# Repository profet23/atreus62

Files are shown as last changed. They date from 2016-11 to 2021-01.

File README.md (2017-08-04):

# atreus62
Design files for the atreus62 keyboard

[Atreus62 components can be purchased from the online store.](http://shop.profetkeyboards.com/category/atreus62)

This keyboad is inspired by the original [atreus keyboard](https://atreus.technomancy.us/).

This version utilizes a Pro Micro for its controller and has a 62 key layout.

## [Build Guide](build-guide/)

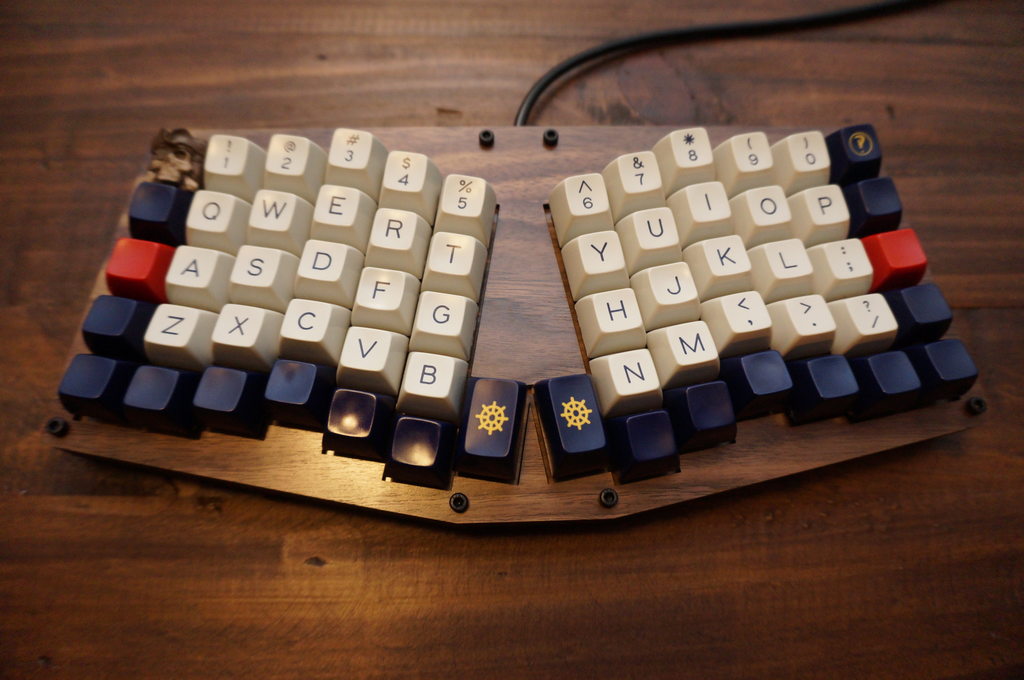
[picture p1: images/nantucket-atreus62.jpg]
Nantucket atreus62


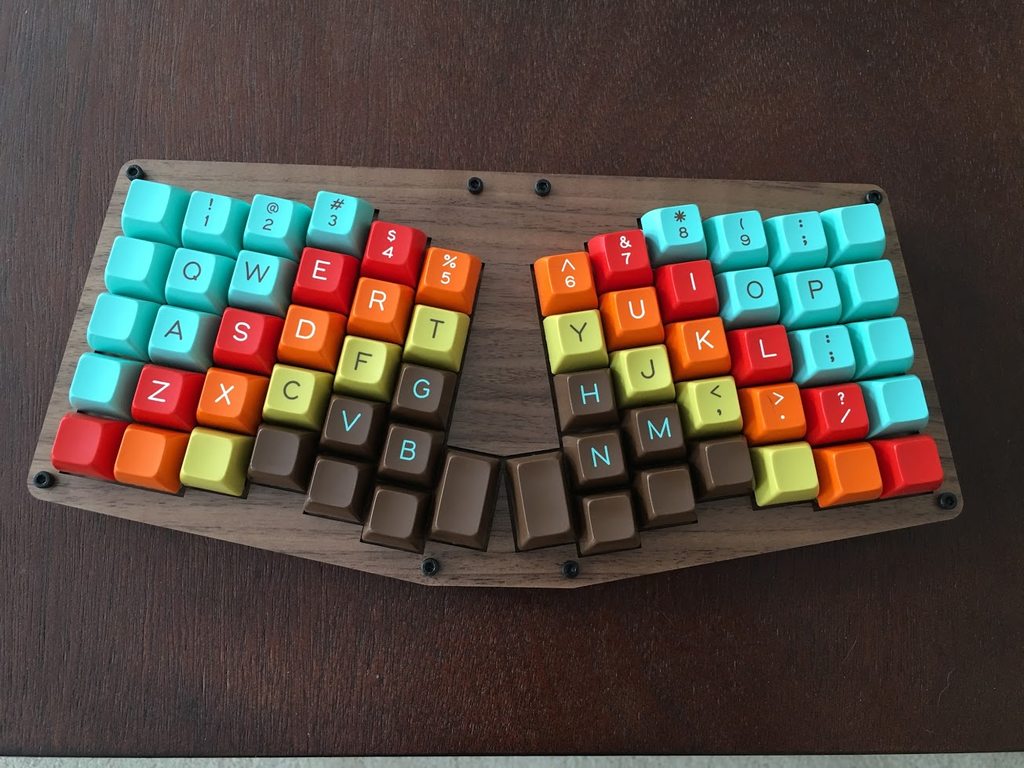
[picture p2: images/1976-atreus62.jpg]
1976 atreus62


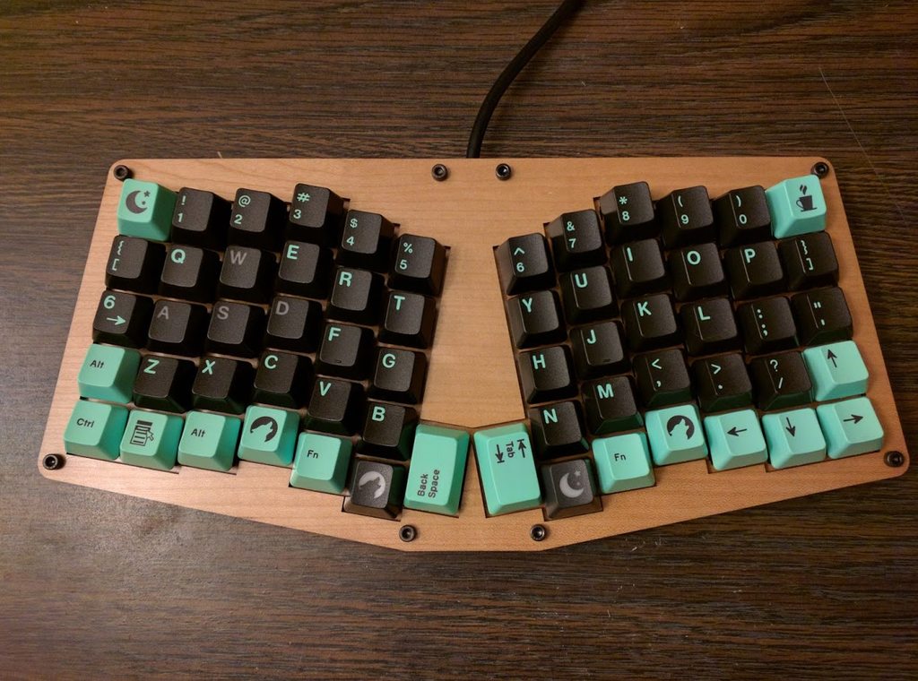
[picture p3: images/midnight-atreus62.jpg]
Midnight atreus62


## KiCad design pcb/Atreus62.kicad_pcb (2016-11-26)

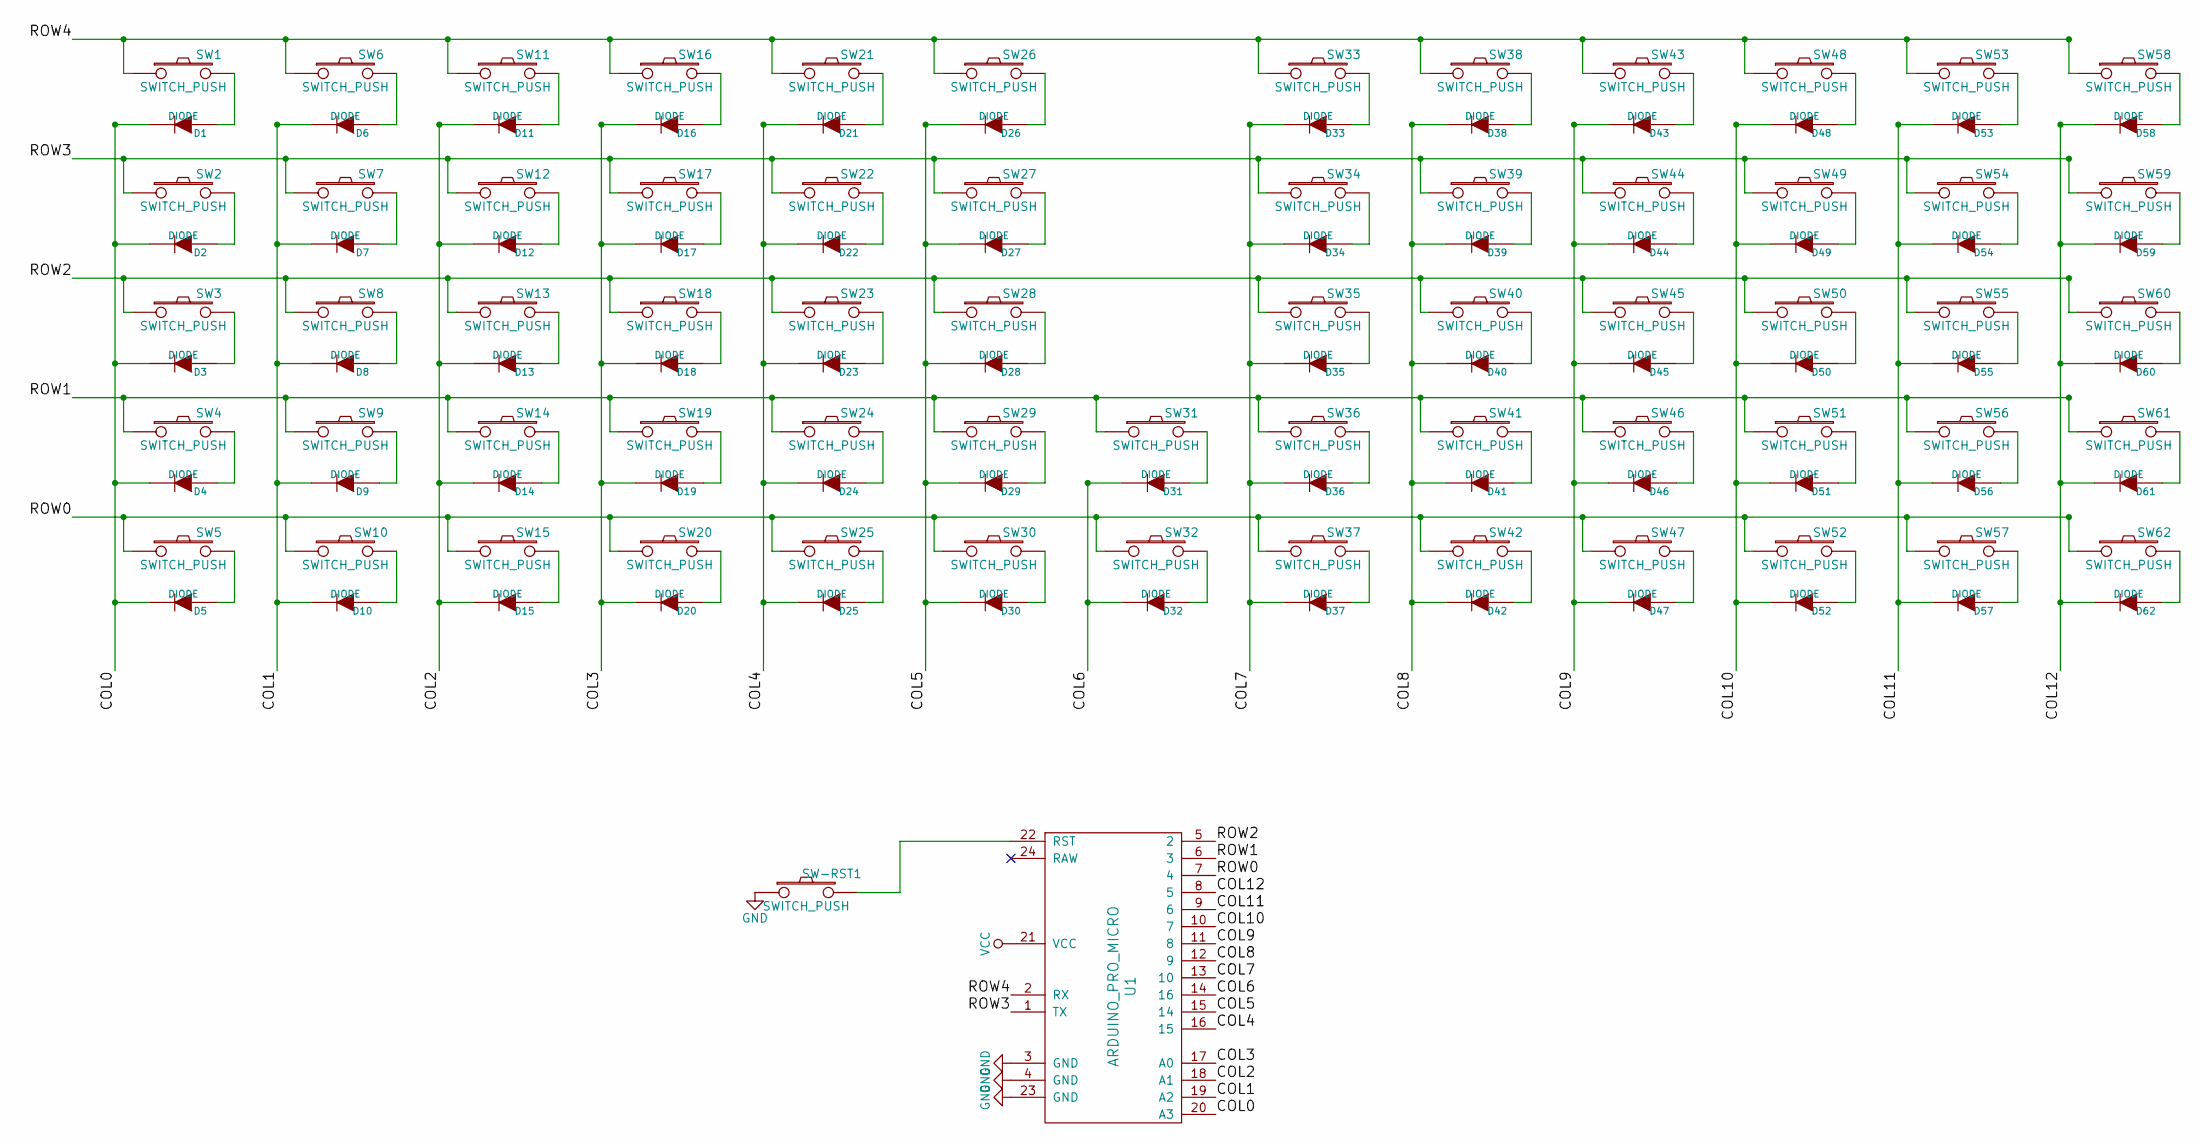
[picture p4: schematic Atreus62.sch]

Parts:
D1, D2, D3, D4, D5, D6, D7, D8, D9, D10, D11, D12, D13, D14, D15, D16, D17, D18, D19, D20, D21, D22, D23, D24, D25, D26, D27, D28, D29, D30, D31, D32, D33, D34, D35, D36, D37, D38, D39, D40, D41, D42, D43, D44, D45, D46, D47, D48, D49, D50, D51, D52, D53, D54, D55, D56, D57, D58, D59, D60, D61, D62: DIODE; SOD-123
SW1, SW2, SW3, SW4, SW5, SW6, SW7, SW8, SW9, SW10, SW11, SW12, SW13, SW14, SW15, SW16, SW17, SW18, SW19, SW20, SW21, SW22, SW23, SW24, SW25, SW26, SW27, SW28, SW29, SW30, SW31, SW32, SW33, SW34, SW35, SW36, SW37, SW38, SW39, SW40, SW41, SW42, SW43, SW44, SW45, SW46, SW47, SW48, SW49, SW50, SW51, SW52, SW53, SW54, SW55, SW56, SW57, SW58, SW59, SW60, SW61, SW62: SWITCH_PUSH; CHERRY_PCB_100H
SW-RST1: SWITCH_PUSH; SW_SPST_B3U-1000P
U1: ARDUINO_PRO_MICRO

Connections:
/COL0: D1.2 (K), D2.2 (K), D3.2 (K), D4.2 (K), D5.2 (K), U1.20 (A3)
/COL1: D6.2 (K), D7.2 (K), D8.2 (K), D9.2 (K), D10.2 (K), U1.19 (A2)
/COL2: D11.2 (K), D12.2 (K), D13.2 (K), D14.2 (K), D15.2 (K), U1.18 (A1)
/COL3: D16.2 (K), D17.2 (K), D18.2 (K), D19.2 (K), D20.2 (K), U1.17 (A0)
/COL4: D21.2 (K), D22.2 (K), D23.2 (K), D24.2 (K), D25.2 (K), U1.16 (15)
/COL5: D26.2 (K), D27.2 (K), D28.2 (K), D29.2 (K), D30.2 (K), U1.15 (14)
/COL6: D31.2 (K), D32.2 (K), U1.14 (16)
/COL7: D33.2 (K), D34.2 (K), D35.2 (K), D36.2 (K), D37.2 (K), U1.13 (10)
/COL8: D38.2 (K), D39.2 (K), D40.2 (K), D41.2 (K), D42.2 (K), U1.12 (9)
/COL9: D43.2 (K), D44.2 (K), D45.2 (K), D46.2 (K), D47.2 (K), U1.11 (8)
/COL10: D48.2 (K), D49.2 (K), D50.2 (K), D51.2 (K), D52.2 (K), U1.10 (7)
/COL11: D53.2 (K), D54.2 (K), D55.2 (K), D56.2 (K), D57.2 (K), U1.9 (6)
/COL12: D58.2 (K), D59.2 (K), D60.2 (K), D61.2 (K), D62.2 (K), U1.8 (5)
/ROW0: SW5.1, SW10.1, SW15.1, SW20.1, SW25.1, SW30.1, SW32.1, SW37.1, SW42.1, SW47.1, SW52.1, SW57.1, SW62.1, U1.7 (4)
/ROW1: SW4.1, SW9.1, SW14.1, SW19.1, SW24.1, SW29.1, SW31.1, SW36.1, SW41.1, SW46.1, SW51.1, SW56.1, SW61.1, U1.6 (3)
/ROW2: SW3.1, SW8.1, SW13.1, SW18.1, SW23.1, SW28.1, SW35.1, SW40.1, SW45.1, SW50.1, SW55.1, SW60.1, U1.5 (2)
/ROW3: SW2.1, SW7.1, SW12.1, SW17.1, SW22.1, SW27.1, SW34.1, SW39.1, SW44.1, SW49.1, SW54.1, SW59.1, U1.1 (TX)
/ROW4: SW1.1, SW6.1, SW11.1, SW16.1, SW21.1, SW26.1, SW33.1, SW38.1, SW43.1, SW48.1, SW53.1, SW58.1, U1.2 (RX)
GND: SW-RST1.1, U1.3 (GND), U1.4 (GND), U1.23 (GND)
unnamed: D1.1 (A), SW1.2
unnamed: D2.1 (A), SW2.2
unnamed: D3.1 (A), SW3.2
unnamed: D4.1 (A), SW4.2
unnamed: D5.1 (A), SW5.2
unnamed: D6.1 (A), SW6.2
unnamed: D7.1 (A), SW7.2
unnamed: D8.1 (A), SW8.2
unnamed: D9.1 (A), SW9.2
unnamed: D10.1 (A), SW10.2
unnamed: D11.1 (A), SW11.2
unnamed: D12.1 (A), SW12.2
unnamed: D13.1 (A), SW13.2
unnamed: D14.1 (A), SW14.2
unnamed: D15.1 (A), SW15.2
unnamed: D16.1 (A), SW16.2
unnamed: D17.1 (A), SW17.2
unnamed: D18.1 (A), SW18.2
unnamed: D19.1 (A), SW19.2
unnamed: D20.1 (A), SW20.2
unnamed: D21.1 (A), SW21.2
unnamed: D22.1 (A), SW22.2
unnamed: D23.1 (A), SW23.2
unnamed: D24.1 (A), SW24.2
unnamed: D25.1 (A), SW25.2
unnamed: D26.1 (A), SW26.2
unnamed: D27.1 (A), SW27.2
unnamed: D28.1 (A), SW28.2
unnamed: D29.1 (A), SW29.2
unnamed: D30.1 (A), SW30.2
unnamed: D31.1 (A), SW31.2
unnamed: D32.1 (A), SW32.2
unnamed: D33.1 (A), SW33.2
unnamed: D34.1 (A), SW34.2
unnamed: D35.1 (A), SW35.2
unnamed: D36.1 (A), SW36.2
unnamed: D37.1 (A), SW37.2
unnamed: D38.1 (A), SW38.2
unnamed: D39.1 (A), SW39.2
unnamed: D40.1 (A), SW40.2
unnamed: D41.1 (A), SW41.2
unnamed: D42.1 (A), SW42.2
unnamed: D43.1 (A), SW43.2
unnamed: D44.1 (A), SW44.2
unnamed: D45.1 (A), SW45.2
unnamed: D46.1 (A), SW46.2
unnamed: D47.1 (A), SW47.2
unnamed: D48.1 (A), SW48.2
unnamed: D49.1 (A), SW49.2
unnamed: D50.1 (A), SW50.2
unnamed: D51.1 (A), SW51.2
unnamed: D52.1 (A), SW52.2
unnamed: D53.1 (A), SW53.2
unnamed: D54.1 (A), SW54.2
unnamed: D55.1 (A), SW55.2
unnamed: D56.1 (A), SW56.2
unnamed: D57.1 (A), SW57.2
unnamed: D58.1 (A), SW58.2
unnamed: D59.1 (A), SW59.2
unnamed: D60.1 (A), SW60.2
unnamed: D61.1 (A), SW61.2
unnamed: D62.1 (A), SW62.2
unnamed: SW-RST1.2, U1.22 (RST)
VCC: U1.21 (VCC)

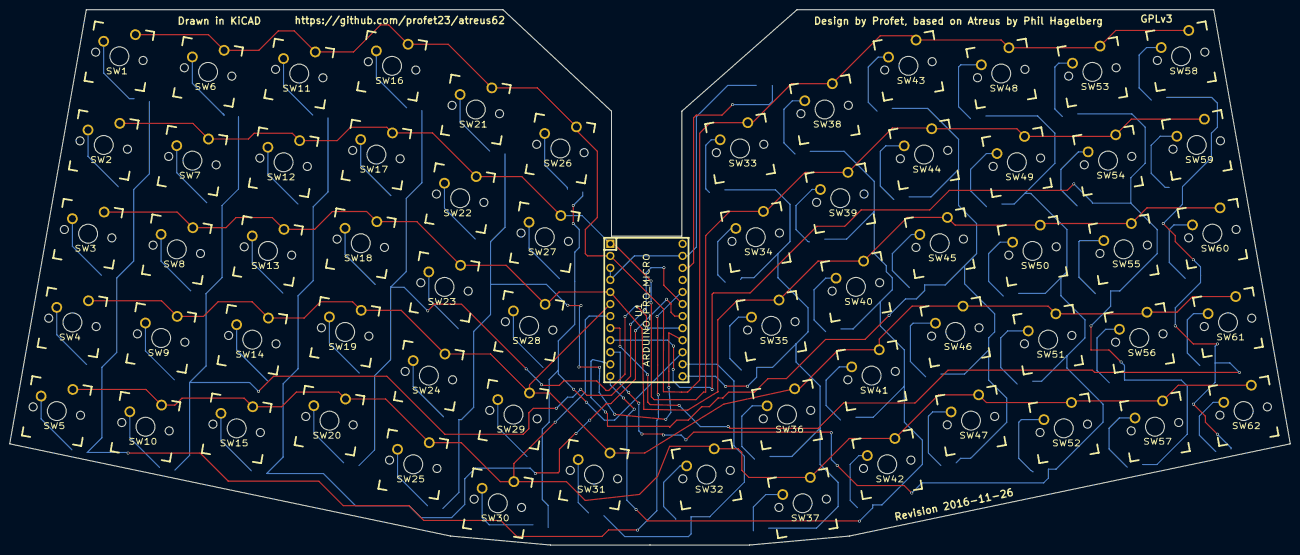
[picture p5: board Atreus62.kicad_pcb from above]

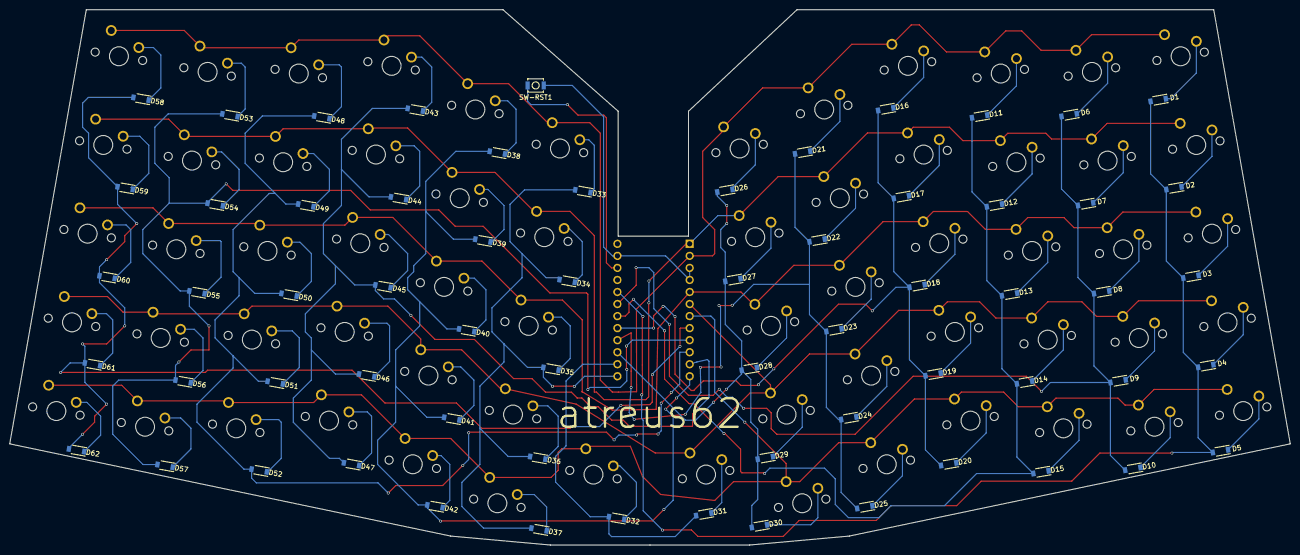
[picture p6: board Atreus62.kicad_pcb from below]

Board: 2 copper layers, 270.1 x 112.9 mm, 126 parts (62 on the bottom side), 82 nets.

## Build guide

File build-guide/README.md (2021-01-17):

# atreus62 Build Guide

Please review all steps carefully before beginning your build.

## Required Components

|Component|Quantity|
|---|:---:|
|[1N4148W-7-F Diodes](http://www.mouser.com/Search/ProductDetail.aspx?R=1N4148W-7-Fvirtualkey62110000virtualkey621-1N4148W-F) |62 (Buy a couple of extra)|
|[Pro Micro with headers](https://www.amazon.com/OSOYOO-ATmega32U4-arduino-Leonardo-ATmega328/dp/B012FOV17O)|1|
|Cherry MX Compatible Switches|62 (Buy a couple of extra)|
|[Micro USB Cable](https://www.amazon.com/AmazonBasics-Micro-USB-USB-2-0-Cable/dp/B013PVKXTS/)|1|
|[Atreus62 PCB](http://shop.profetkeyboards.com/product/atreus62-pcb)|1|
|[Atreus62 Case](http://shop.profetkeyboards.com/product/atreus62-case)|1|
|[Omrom B3U-1000P](https://www.mouser.com/ProductDetail/653-B3U-1000P/)|1 (Optional)|

##  PCB Assembly

## Step 1
Program the Pro Micro with your firmware. [QMK supports the Atreus62.](https://github.com/jackhumbert/qmk_firmware)

#### For information on compiling QMK please consult QMK documentation.

We're going to assume that you already have a .hex file called firmware.hex that you want to flash on to your Pro Micro.

In order to flash the device, you need to figure out which "serial port" your device is attached to. First of all, identify what serial devices (including virtual ones) are currently connected to your machine with this command:

```
ls /dev/tty*
```

On my machine, this produces the following:

```
/dev/tty    /dev/tty12  /dev/tty17  /dev/tty21  /dev/tty26  /dev/tty30 /dev/tty35  /dev/tty4   /dev/tty44  /dev/tty49  /dev/tty53  /dev/tty58 /dev/tty62  /dev/ttyS0
    /dev/tty0   /dev/tty13  /dev/tty18  /dev/tty22  /dev/tty27  /dev/tty31 /dev/tty36  /dev/tty40  /dev/tty45  /dev/tty5   /dev/tty54  /dev/tty59 /dev/tty63  /dev/ttyS1
    /dev/tty1   /dev/tty14  /dev/tty19  /dev/tty23  /dev/tty28  /dev/tty32 /dev/tty37  /dev/tty41  /dev/tty46  /dev/tty50  /dev/tty55  /dev/tty6  /dev/tty7   /dev/ttyS2
    /dev/tty10  /dev/tty15  /dev/tty2   /dev/tty24  /dev/tty29  /dev/tty33 /dev/tty38  /dev/tty42  /dev/tty47  /dev/tty51  /dev/tty56  /dev/tty60 /dev/tty8   /dev/ttyS3
    /dev/tty11  /dev/tty16  /dev/tty20  /dev/tty25  /dev/tty3   /dev/tty34 /dev/tty39  /dev/tty43  /dev/tty48  /dev/tty52  /dev/tty57  /dev/tty61 /dev/tty9   /dev/ttyUSB0
```

I run Debian, so this will likely be different for you if you use something else. Take a note of the output, we'll need it later.

#### If you've never flashed your device before:

If this is your first time flashing the Pro Micro, this part will be easy. On the Pro Micro's first boot, instead of trying to run code (that you haven't uploaded yet!), it just sticks in bootloader mode. So if you only want to flash firmware once and forget about it - good news.

Just plug in your device and it should automatically go into bootloader mode.

#### If you have previously flashed your device:

If you've previously flashed your Pro Micro, instead of going straight into bootloader mode it will try to run the code that you uploaded to it. To go into bootloader mode, you need to quickly connect the GND + RST pins twice, just as the device powers on.

Next, plug in your device and re-run the command, the same as before:

```
ls /dev/tty*
```

There should be one more output device than was seen previously. For me, it's `/dev/ttyACM0`.

To flash the device, you need to have AVRdude installed. On Linux, you can do this with your normal package manager. On Mac OS, I've heard from a reputable source that you need to install CrossPack.

Once it's installed, confirm that it works by just running avrdude on the command-line. It should throw some errors. If so, it works.

Once you have AVRdude set up, navigate to the directory with your .hex file in it. Then, run the following:

```
avrdude -p atmega32u4 -P YOUR_SERIAL_PORT  -c avr109  -U flash:w:filename.hex
```

Of course, replace YOUR_SERIAL_PORT with your serial port's device name, and filename.hex with the appropriate filename. For me, this line looks like this:

```
avrdude -p atmega32u4 -P /dev/ttyACM0  -c avr109  -U flash:w:Soarer_at2usb_v1.12_atmega32u4.hex
```

If it says ''device not in sync'' or similar, your device is no longer in bootloader mode. Unplug it, and get it back into bootloader mode like you did in the previous step, and try again.

### Step 2
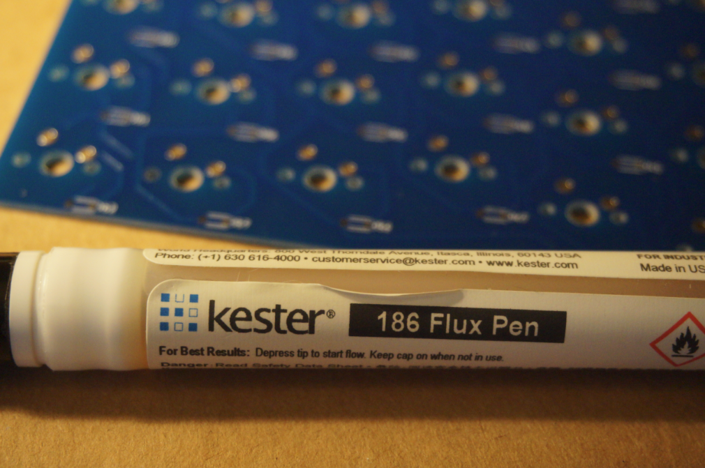
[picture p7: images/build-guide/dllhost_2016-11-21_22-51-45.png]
Step2


### Step 3
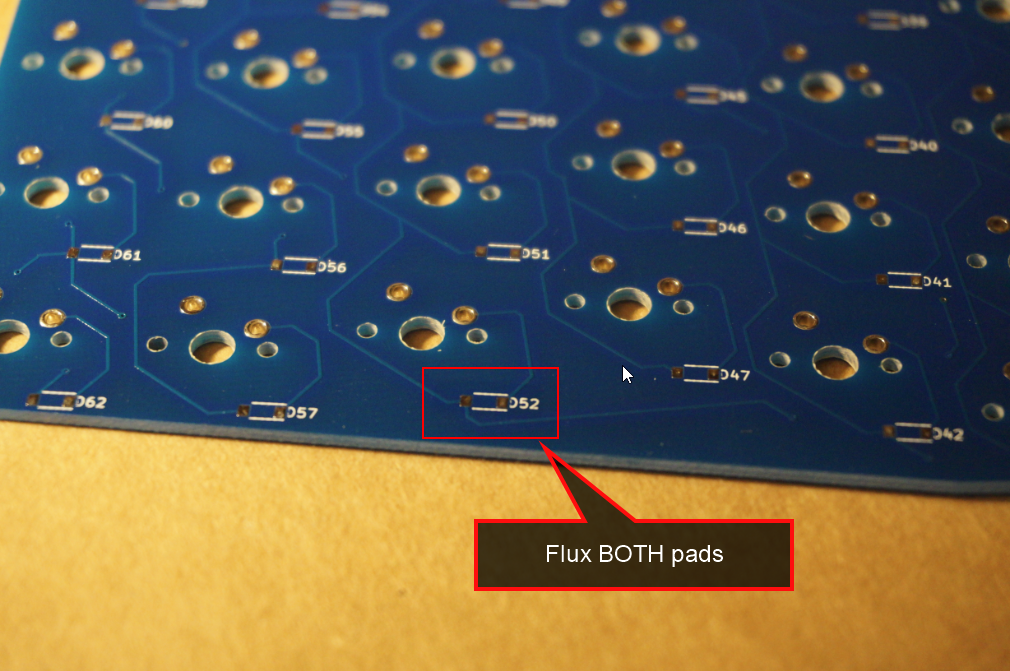
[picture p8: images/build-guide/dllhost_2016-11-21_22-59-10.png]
Step3


### Step 4
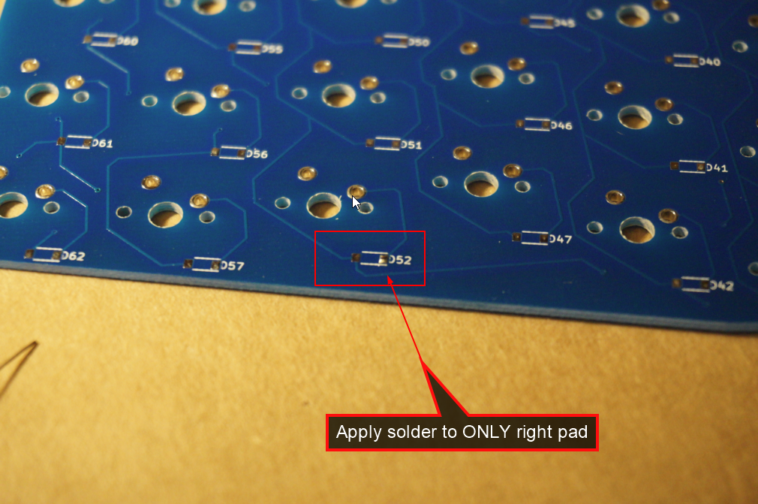
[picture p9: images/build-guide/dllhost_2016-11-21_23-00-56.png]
Step4


### Step 5
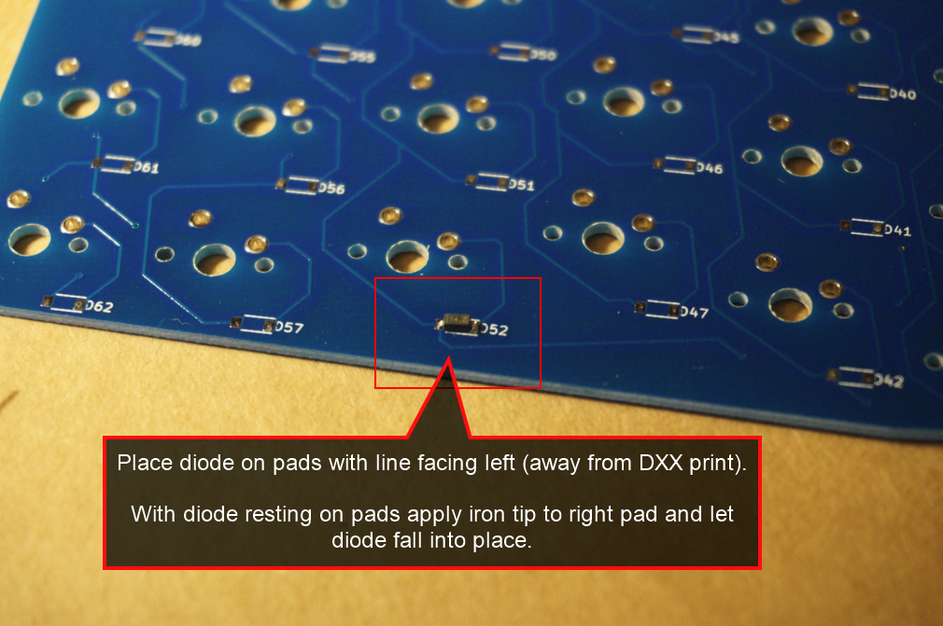
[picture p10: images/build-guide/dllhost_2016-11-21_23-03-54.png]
Step5


### Step 6
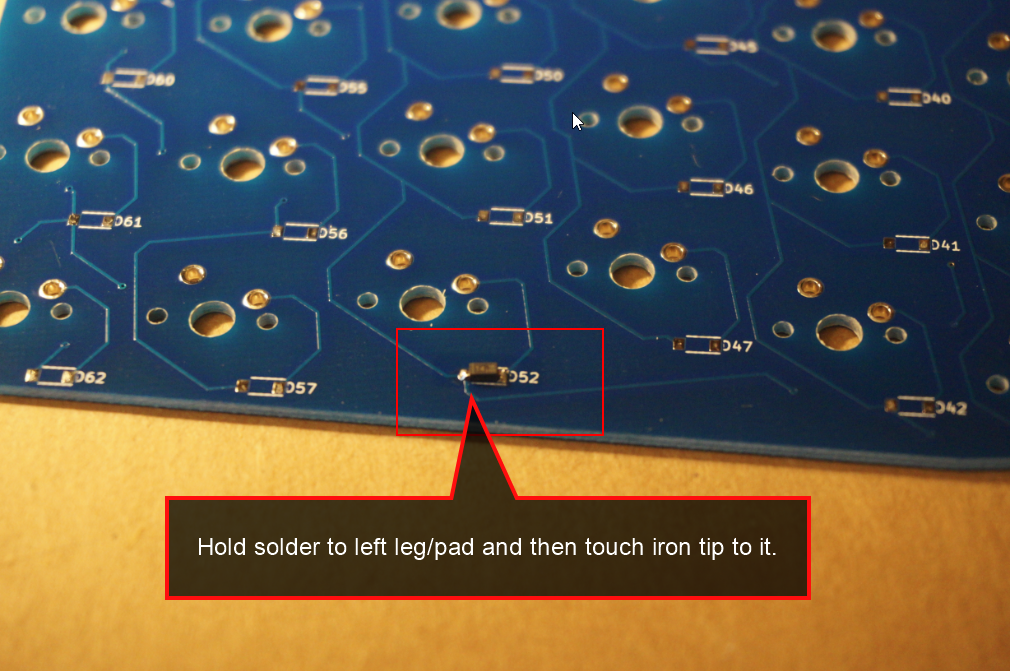
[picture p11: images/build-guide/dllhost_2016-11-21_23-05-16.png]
Step6


### Step 7
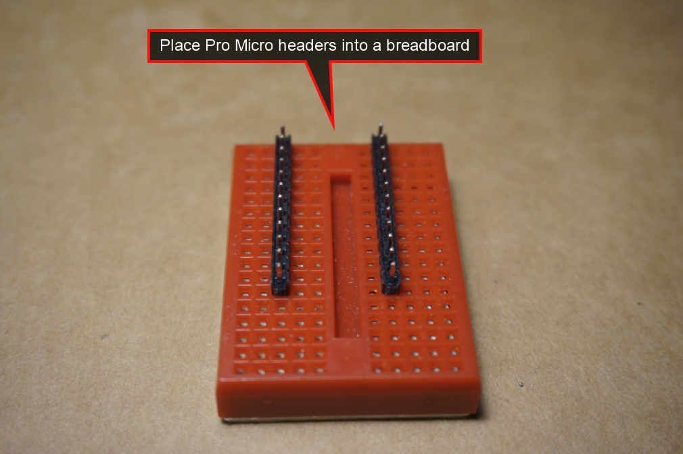
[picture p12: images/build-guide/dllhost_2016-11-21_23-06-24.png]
Step7


### Step 8
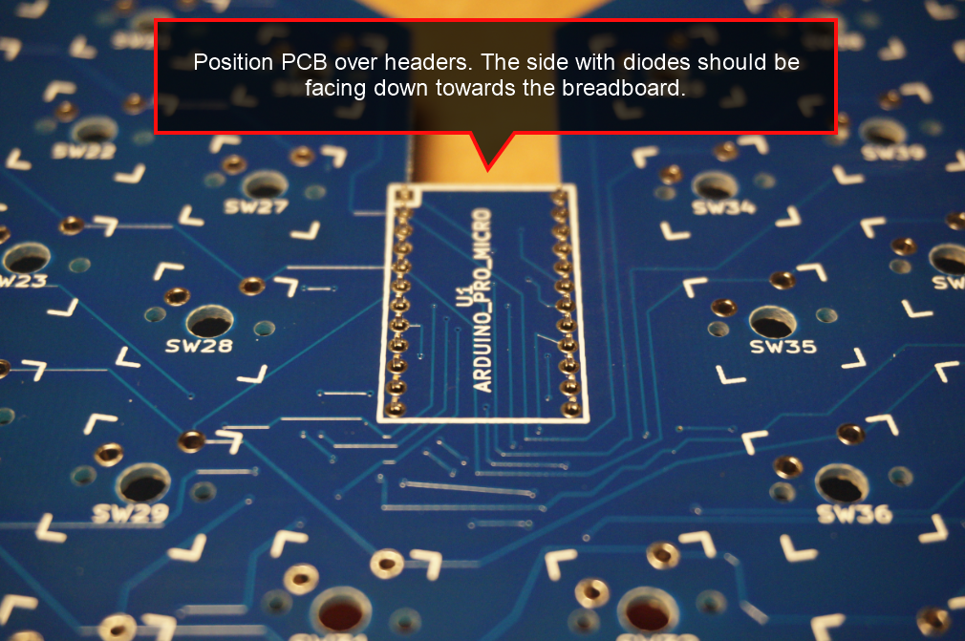
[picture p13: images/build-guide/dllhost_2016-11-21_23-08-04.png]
Step8


### Step 9
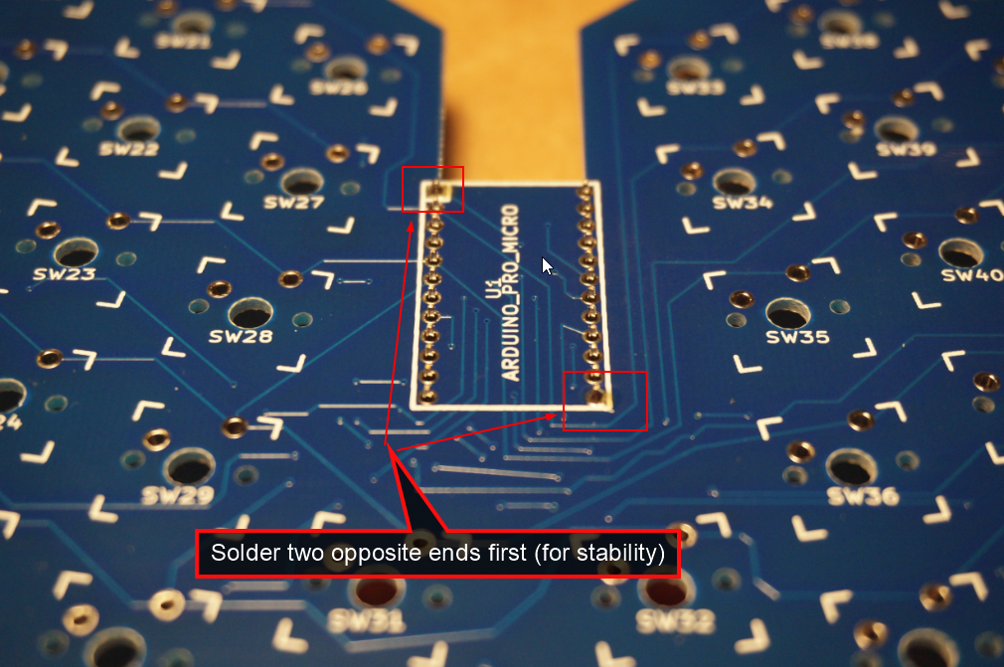
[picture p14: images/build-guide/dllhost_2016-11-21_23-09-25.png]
Step9


### Step 10
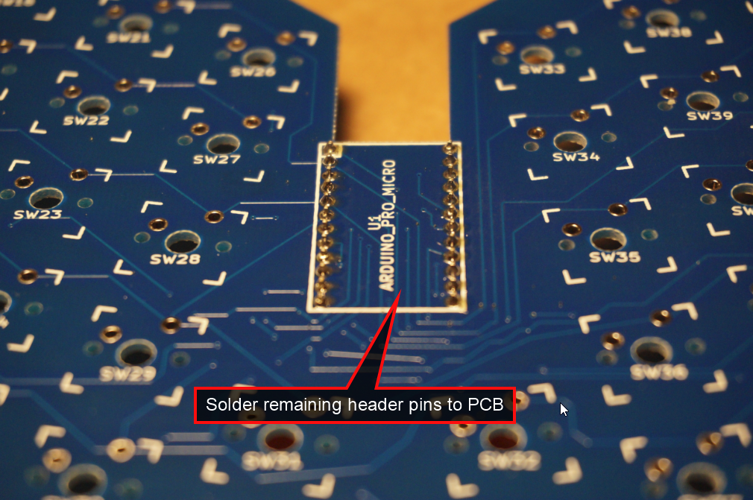
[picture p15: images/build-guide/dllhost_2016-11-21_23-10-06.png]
Step10


### Step 11
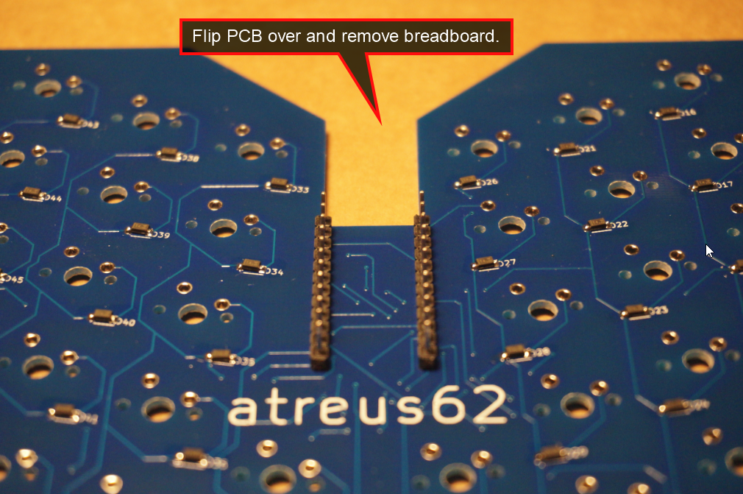
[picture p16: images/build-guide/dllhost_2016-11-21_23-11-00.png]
Step11


### Step 12
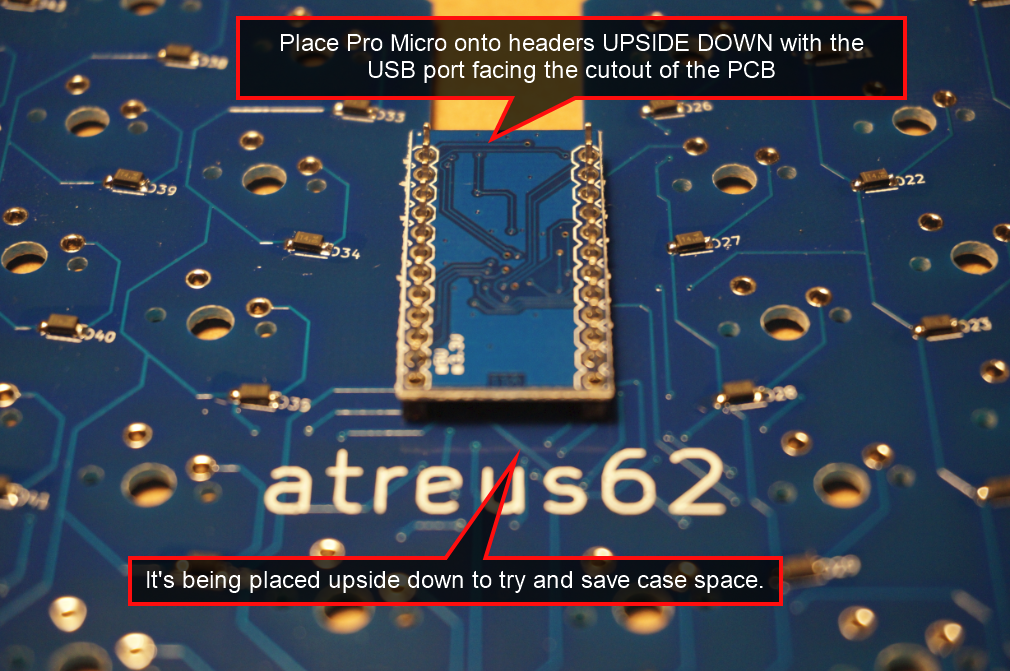
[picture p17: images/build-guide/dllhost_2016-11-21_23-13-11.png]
Step12


### Step 13
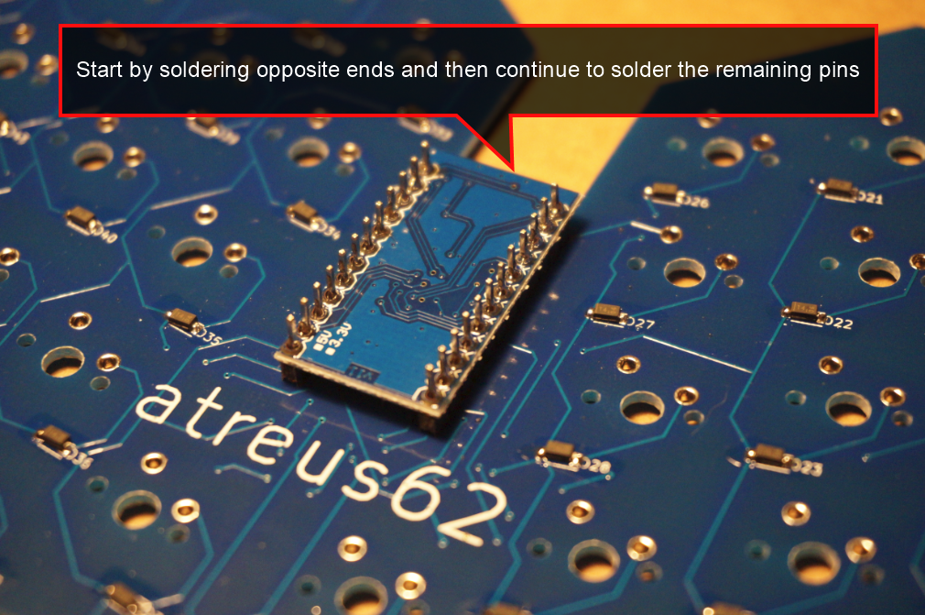
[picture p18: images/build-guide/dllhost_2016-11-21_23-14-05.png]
Step13


### Step 14
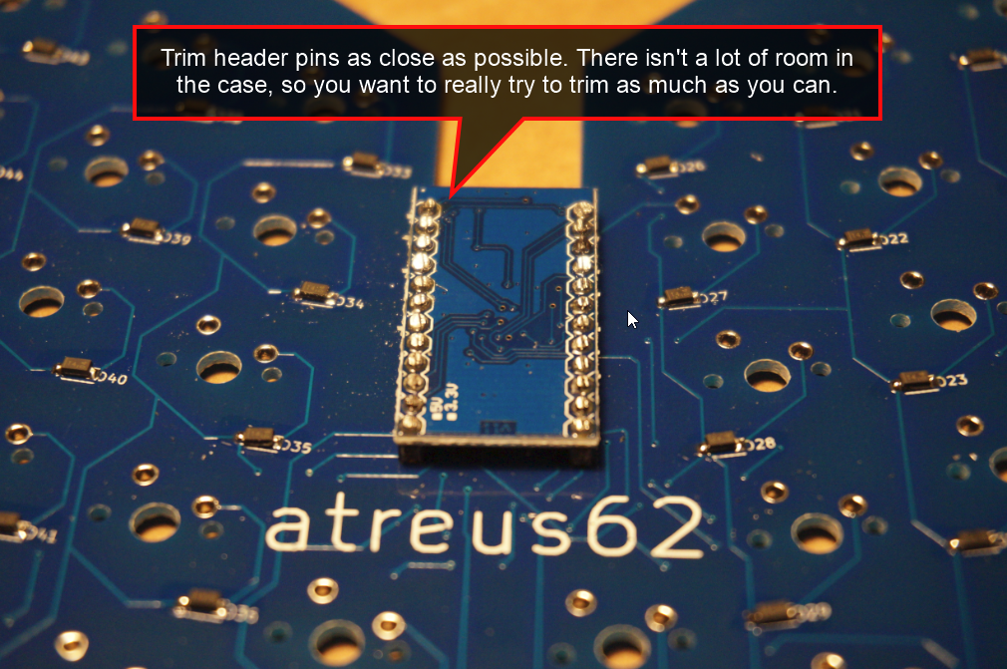
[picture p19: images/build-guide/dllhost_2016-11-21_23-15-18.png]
Step14


### Step 15
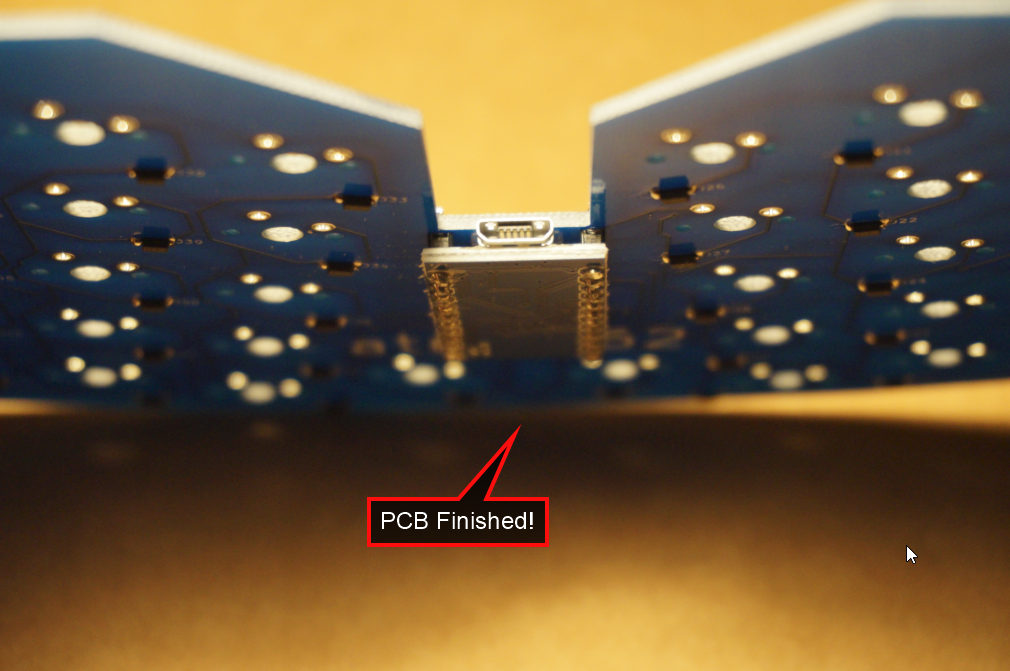
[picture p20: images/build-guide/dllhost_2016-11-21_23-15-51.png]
Step15


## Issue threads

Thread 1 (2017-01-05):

Case layer thickness

rushfrisby, 2017-01-05:
For the walnut boards you are making what thickness are you cutting each of the case layers?

rushfrisby, 2017-01-05:
This board is gorgeous btw! 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

What kind of walnut wood is that? Does the wood dent easily? Are the caps stable enough in a wood plate or is there wobble? Sorry for all the questions, I've never used a wood board before but I want to give it a try.

RagingRoosevelt, 2017-03-11:
The thickness of the bottom layer shouldn't matter.  The thicker it is, the stronger it'll be, but that's just a judgement call.

The thickness of the switch plate is a standardized amount which is determined by the switches.  For Cherry MX, I think you want something around 1.5mm.  The switch plate should be metal so that it is sufficiently sturdy.

The thickness of the spacer should accommodate the bottom of the switches (the part that hangs below the switch plate) and the PCB.  On my ergodox, that's ~7.75-8mm.  On my Atreus (not 62), the spacer is around 6mm, although my Atreus has a thicker switch plate than normal..  The thicker you make it, the more clearance you'll have.

The top plate can be however thick you want or you can skip it entirely.  I wouldn't make it more than about 8mm thick, though, since then it would stick above your caps.

julowe, 2017-03-13:
Via email from @profet23 :

> I use uniform 3.5mm wood plates for my wood cases.
> I use (from top to bottom) 3mm, 4.5mm, 4.5mm, 3mm, 3mm for acrylic builds.

So my rough interpretation using the below picture as a guide (without actually building this myself yet) is one 3mm black acrylic for [top plate](https://github.com/profet23/atreus62/blob/master/case/atreus62_top_plate.svg) (unseen in below pic), one clear acrylic [switch plate](https://github.com/profet23/atreus62/blob/master/case/atreus62_switch_plate.svg) at 4.5mm thick, one clear acrylic [spacer layer](https://github.com/profet23/atreus62/blob/master/case/atreus62_spacer.svg) at 4.5mm thick, one 3mm thick black acrylic [spacer layer](https://github.com/profet23/atreus62/blob/master/case/atreus62_spacer.svg), and one 3mm clear acrylic [full surface bottom layer](https://github.com/profet23/atreus62/blob/master/case/atreus62_bottom_plate.svg).

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
[Case at Profet Shop](http://shop.profetkeyboards.com/product/atreus62-case)

Let me know if that makes sense, and/or I'll update this if I build it.

Closed 2017-03-15.

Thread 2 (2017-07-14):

Screws and nuts?

kgraves, 2017-07-14:
Hey @profet23, I'm starting to buy stuff to build my first atreus62. I'm printing the case for my first run, but don't see any mention of screw size you're using. Any help here?

profet23, 2017-07-15:
M3 x20mm

Closed 2017-07-15.

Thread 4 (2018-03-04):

trouble finding `/dev/tty*` port with a macbook pro (usb-c)

tatums, 2018-03-04:
I had some trouble finding the correct tty port.  I'm using a macbook pro which has usb-c ports.

#### background/context
* I ordered mine prebuild so the micro controller was already programmed.
* Since the macbook has usb-c ports I'm using an [apple usb dongle](https://www.apple.com/shop/product/MJ1K2AM/A/usb-c-digital-av-multiport-adapter)

#### Here's how I found the correct tty port.
* First, flip the keyboard over and use a paperclip to hit keyboards reset button.
* Then, you [have ~8 seconds where the micro controller](https://learn.sparkfun.com/tutorials/pro-micro--fio-v3-hookup-guide/troubleshooting-and-faq#ts-reset) is viewable using `ls /dev/tty*`.  After 8 seconds it's no longer viewable. In my case it appears as `/dev/tty.usbmodem14411`

BTW, feel free to close this issue.  I'm only sharing because it wasn't immediately obvious to me and I thought others may find this helpful.

profet23, 2018-05-10:
If you want, you could submit a pull request with documentation updates. For now I'll close this issue.

Closed 2018-05-10.

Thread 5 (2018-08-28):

CAD-files are cut off

R4WBIT, 2018-08-28:
Looking to print out an Atreus62 and when I tried to use the cad files available I saw that they were cut off, only displaying one half.

Is it possible to fix these or make a DXF-file available for all layers?
Thanks!

profet23, 2018-08-28:
What program are you using?  Try [inkscape](https://inkscape.org)

R4WBIT, 2018-08-29:
Oh, that seem to have worked.
Thanks!

Also, when exporting to dxf, what dimensions should be used?
Inches? Millimetre?
Or is it not according to scale?

profet23, 2018-08-29:
Depends on how you'r'e exporting? What are you trying to do? Why not just use the svg's? dxf's do not have units.

R4WBIT, 2018-08-29:
I'm exporting via Inkscape. I have to do it as the laser-cutting company only takes dxf as a file option.
Did not know that they don't include units.
I'll just import the dxf at the lasercutting-site and resize it there.

What's the dimensions for the atreus? (length, height etc.).
Can't find them in the repo.

Thanks for the patience.

profet23, 2018-08-29:
Open the svg in inkscape and use the ruler to get the exact dimensions you're looking for.

profet23, 2018-08-29:
You ok with closing this issue now?

R4WBIT, 2018-08-29:
Oh yeah, I see now.
Thanks.

profet23, 2018-08-29:
Also... if you're looking for a custom case cut... hit me up here:  https://shop.profetkeyboards.com/custom-builds

Closed 2018-08-29.

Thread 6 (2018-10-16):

Struggling to flash firmware

owenstranathan, 2018-10-16:
I realize GH is probably not the best place for this but here I go anyway.

I am using a promicro clone from here https://www.amazon.com/gp/product/B012FOV17O/ref=oh_aui_detailpage_o08_s00?ie=UTF8&psc=1

I am not able to flash my modified firmware nor the default firmware onto the board using avrdude on a mac. (I have also tried avrdudess on my windows machine at work to similar effect)

I run the following command

```
$ avrdude -p atmega32u4 -P /dev/cu.usbmodem1421 -c avr109 -U flash:w:atreus62_default.hex
```

and the output is like so

```
Connecting to programmer: .
Found programmer: Id = "CATERIN"; type = S
    Software Version = 1.0; No Hardware Version given.
Programmer supports auto addr increment.
Programmer supports buffered memory access with buffersize=128 bytes.

Programmer supports the following devices:
    Device code: 0x44

avrdude: AVR device initialized and ready to accept instructions

Reading | ################################################## | 100% 0.00s

avrdude: Device signature = 0x1e9587 (probably m32u4)
avrdude: NOTE: "flash" memory has been specified, an erase cycle will be performed
         To disable this feature, specify the -D option.
avrdude: erasing chip
avrdude: reading input file "atreus62_default.hex"
avrdude: input file atreus62_default.hex auto detected as Intel Hex
avrdude: ERROR: address 0x800224 out of range at line 1083 of atreus62_default.hex
avrdude: read from file 'atreus62_default.hex' failed

avrdude: safemode: Fuses OK (E:CB, H:D8, L:FF)

avrdude done.  Thank you.

```

This is my first build and in my naivete I went ahead and soldered the board to the wiring before programmimg it. I was initially certain that I had just gotten a melon board, but I've bought 2 other boards and had the same issues (So the problems is probably me)

I would really appreciate help on this.

profet23, 2018-10-16:
You said you've tried multiple pro micros?

owenstranathan, 2018-10-17:
@profet23 Hey Thanks for responding. I also posted this question in `/r/olkb` and someone over there knew exactly the issue. https://www.reddit.com/r/olkb/comments/9ong7q/trouble_flashing_pro_micro_clone/

Apparently it's a bug in avr-gcc 8.2 (I'm not familiar with exact nature of the bug, other than it obviously  tries to access disallowed segments of memory) But switching to avr-gcc 7.X  and recompiling got me rolling. The only other problem I encountered was my columns were in revers order (probably I just wired it backwards, I had to use a separate source for translating the pinnout from teensy to promicro) i just reversed the column order in `config.h` and I was fine.

If anyone else comes here in the future the *TL;DR* is:

* Check your avr-gcc version: `avr-gcc --version`
* If it's 8.2 uninstall and reinstall at 7.X or lower
* recompile and flash again

Thanks again for trying to help me! And thanks for the great design!

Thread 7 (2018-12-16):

Any way to add WS2812b support? Multiplex a pin?

jsmestad, 2018-12-16:
It appears all pins on the pro micro are used for the key matrix. Have you done any builds or mods to support RGB anywhere (like a WS2812b)? I am new to QMK and wasnt sure if the matrix scanning code could support pin multiplexing without impacting the matrix scanning code. Any ideas or am I out of luck?

profet23, 2021-01-17:
Yes. RGB can be supported. I recommend using an Elite-C controller instead of a pro-micro for this.

QMK firmware for elite-c and RGB underglow:  https://github.com/profet23/qmk_firmware/tree/atreus62_rgb.

Uses Elite-C Pin B7 and 31 RGB LEDs from a WS2812B strip.

Closed 2021-01-17.

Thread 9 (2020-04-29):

build guide does not mention reset switch

yodrew, 2020-04-29:
Hi, the build guide does not mention the reset switch listed as one of the electronic components in the store. It is obvious what to do with the switch, like it just plugs in by hand? Thank you for your beautiful keyboards. Can't wait to put one together.

benwalk, 2021-01-17:
I've also encountered this. I bought the PCB and sourced the components separately based on the build guide. However, the PCB has a `SW-RST1` space, which lines up with the hole in the case (nice feature!) but I didn't order a button because it was not mentioned. I'm not exactly sure which button is intended to go there (I'm not experienced by any means with this) - @profet23 would you be able to provide any more information about which part to order for this space?

profet23, 2021-01-17:
Added.

Closed 2021-01-17.

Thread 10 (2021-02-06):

KC_LCAP does not seem to working as expected

sfnvm, 2021-02-06:
Hi there. Just got my keyboard yesterday, everything seem to working fine except when I'm remapping the layouts (adding caps lock key (layer 0), lock caps lock (layer 1)) and keyboard's behaving like [this](https://www.reddit.com/r/olkb/comments/7b9wbk/qmkhelp_programming_a_locking_switch/)

**Current layout**
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

profet23, 2021-02-06:
I'm not entirely sure what you're asking.

If the switches are working as intended with the standard firmware, and you can't get your desired functionality with a custom qmk firmware layout, this is probably a question for the qmk forums.

sfnvm, 2021-02-06:
@profet23 Right, thank you for your time.

Closed 2021-02-06.

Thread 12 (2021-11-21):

Geometry differences between case and PCB

possibilities, 2021-11-21:
I noticed that the PCB distance between keys from one side to another is slightly different on the PCB and the case. I checked this by measuring the distance between the middle of the upper left key center and the upper right key center.

Case: 221.648mm
PCB: 223.980mm

I assume it all works when cut and PCBs are generated because the difference is very small. Is it by design? If not would it be worth taking the time to match them? I think the case geometry is more "correct" and the solution is to move PBC key centers to match?

Happy to go ahead and do the work and submit an MR if it makes sense, let me know.

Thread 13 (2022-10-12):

Case files not matching with the PCB

OlliGranlund, 2022-10-12:
I noticed that the case files do not match with the PCB files. The PCB is alright but the seems like it's not scaled right + you cannot fit switches in the switch plate with the current dimensions.

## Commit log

2016-11-16 Adding initial design files for PCB and Case
    [Atreus62.kicad_pcb, Atreus62.sch]
2016-11-26 Adding reset switch to PCB
    [Atreus62.kicad_pcb, Atreus62.sch]
2016-11-26 Adding reset hole to bottom plate.
2021-01-17 Update README.md
    Adding reset switch to list of components.

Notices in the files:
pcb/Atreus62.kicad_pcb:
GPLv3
